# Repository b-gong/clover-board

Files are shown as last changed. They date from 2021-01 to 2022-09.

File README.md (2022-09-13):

# clover-board
Important: This is more of a proof of concept for me and needs a lot of improvement.
- No hotswap; and hotswap sockets don't work because the plate is misaligned by fractions of a mm
- Not a big fan of the layout anymore, too big

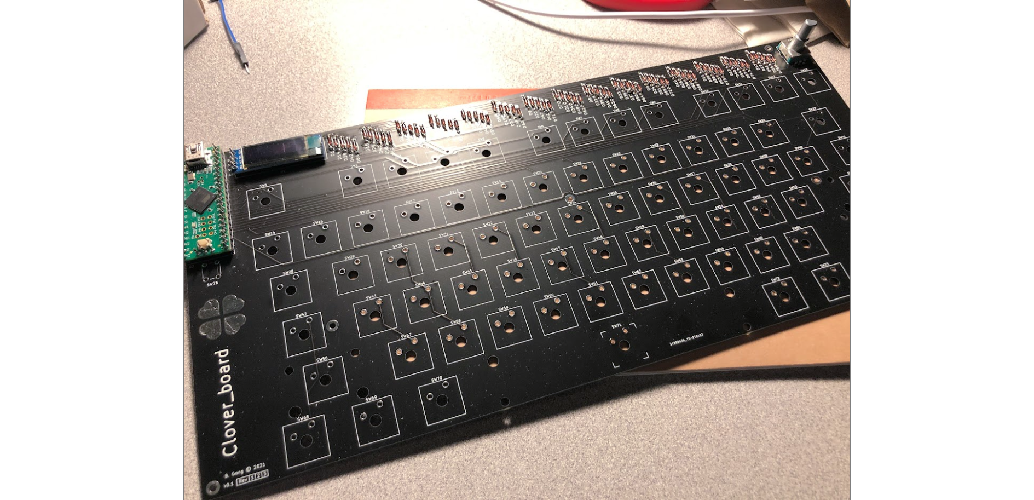
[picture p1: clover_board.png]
Picture of manufactured board


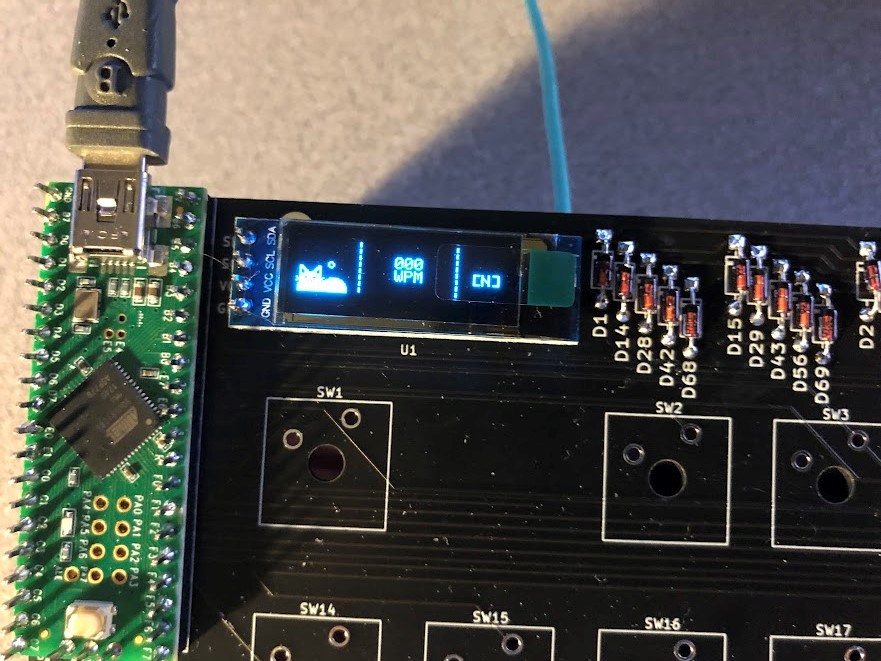
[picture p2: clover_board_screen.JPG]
Picture of OLED screen


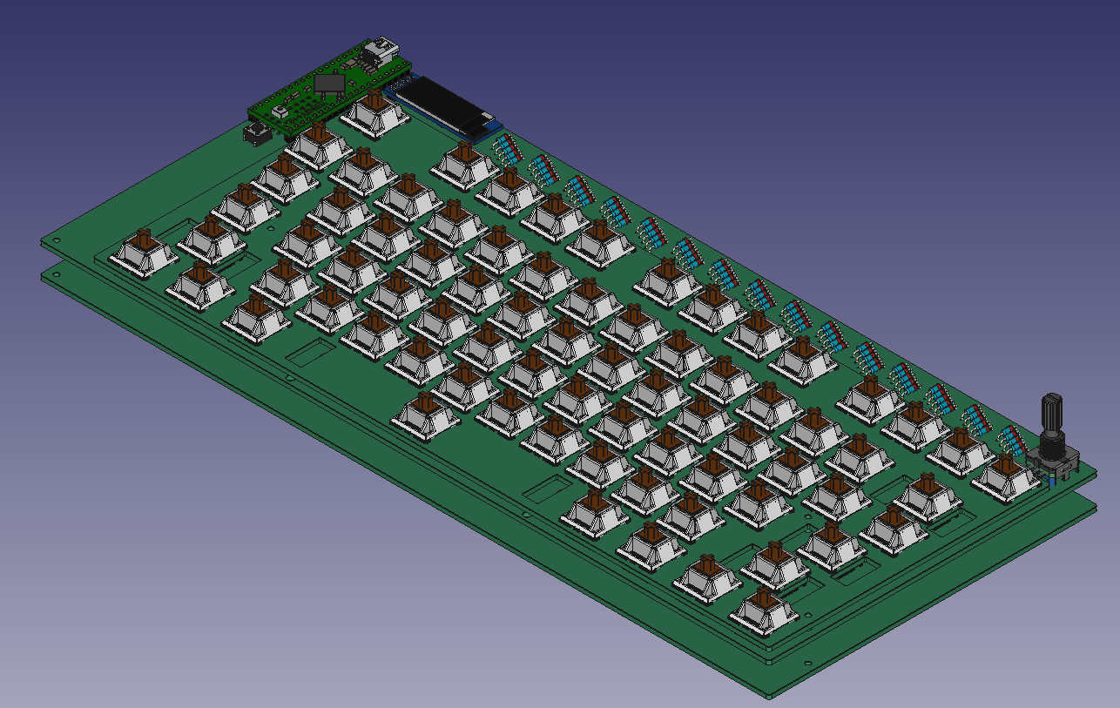
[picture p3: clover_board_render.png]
FreeCAD Screenshot of clover_board made with KiCadStepUp Addon


### 60% + Function Keys with OLED screen and rotary encoder
Who needs the rest of the keyboard xd

### Exposed diodes and Pro Micro for a e s t h e t i c s
Looks sexy

### Namesake of the board (so cute!)
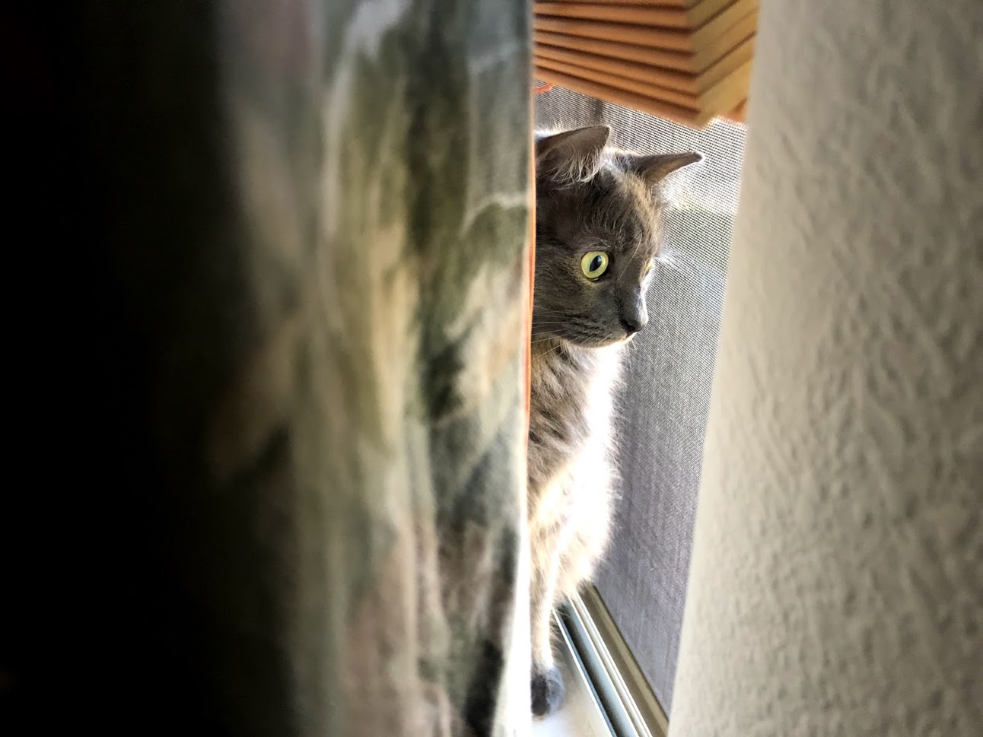
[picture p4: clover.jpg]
Picture of Clover the cat


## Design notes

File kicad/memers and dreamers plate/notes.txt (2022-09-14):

x: [-7.69, 300.51]
y: [32.955, 171.955]

side legnth of square in plate = 270.64375 - 284.64375 = 14mm

distance from rctrl to right and bottom edges in pcb (repectively) = 5.21mm 2.54mm

x coord of rctrl right edge = 300.99-5.21 = 295.78
y coord of rctrl bottom edge = 172.085-2.54 = 169.545

screw holes:
19.5 36.5
280.5 36.5
148.25	95.25 (on plate)
42 124 (on plate)
261 116 (on plate)
-4 168.5
297 152 (on plate)

+5.51 171.955-164.0625

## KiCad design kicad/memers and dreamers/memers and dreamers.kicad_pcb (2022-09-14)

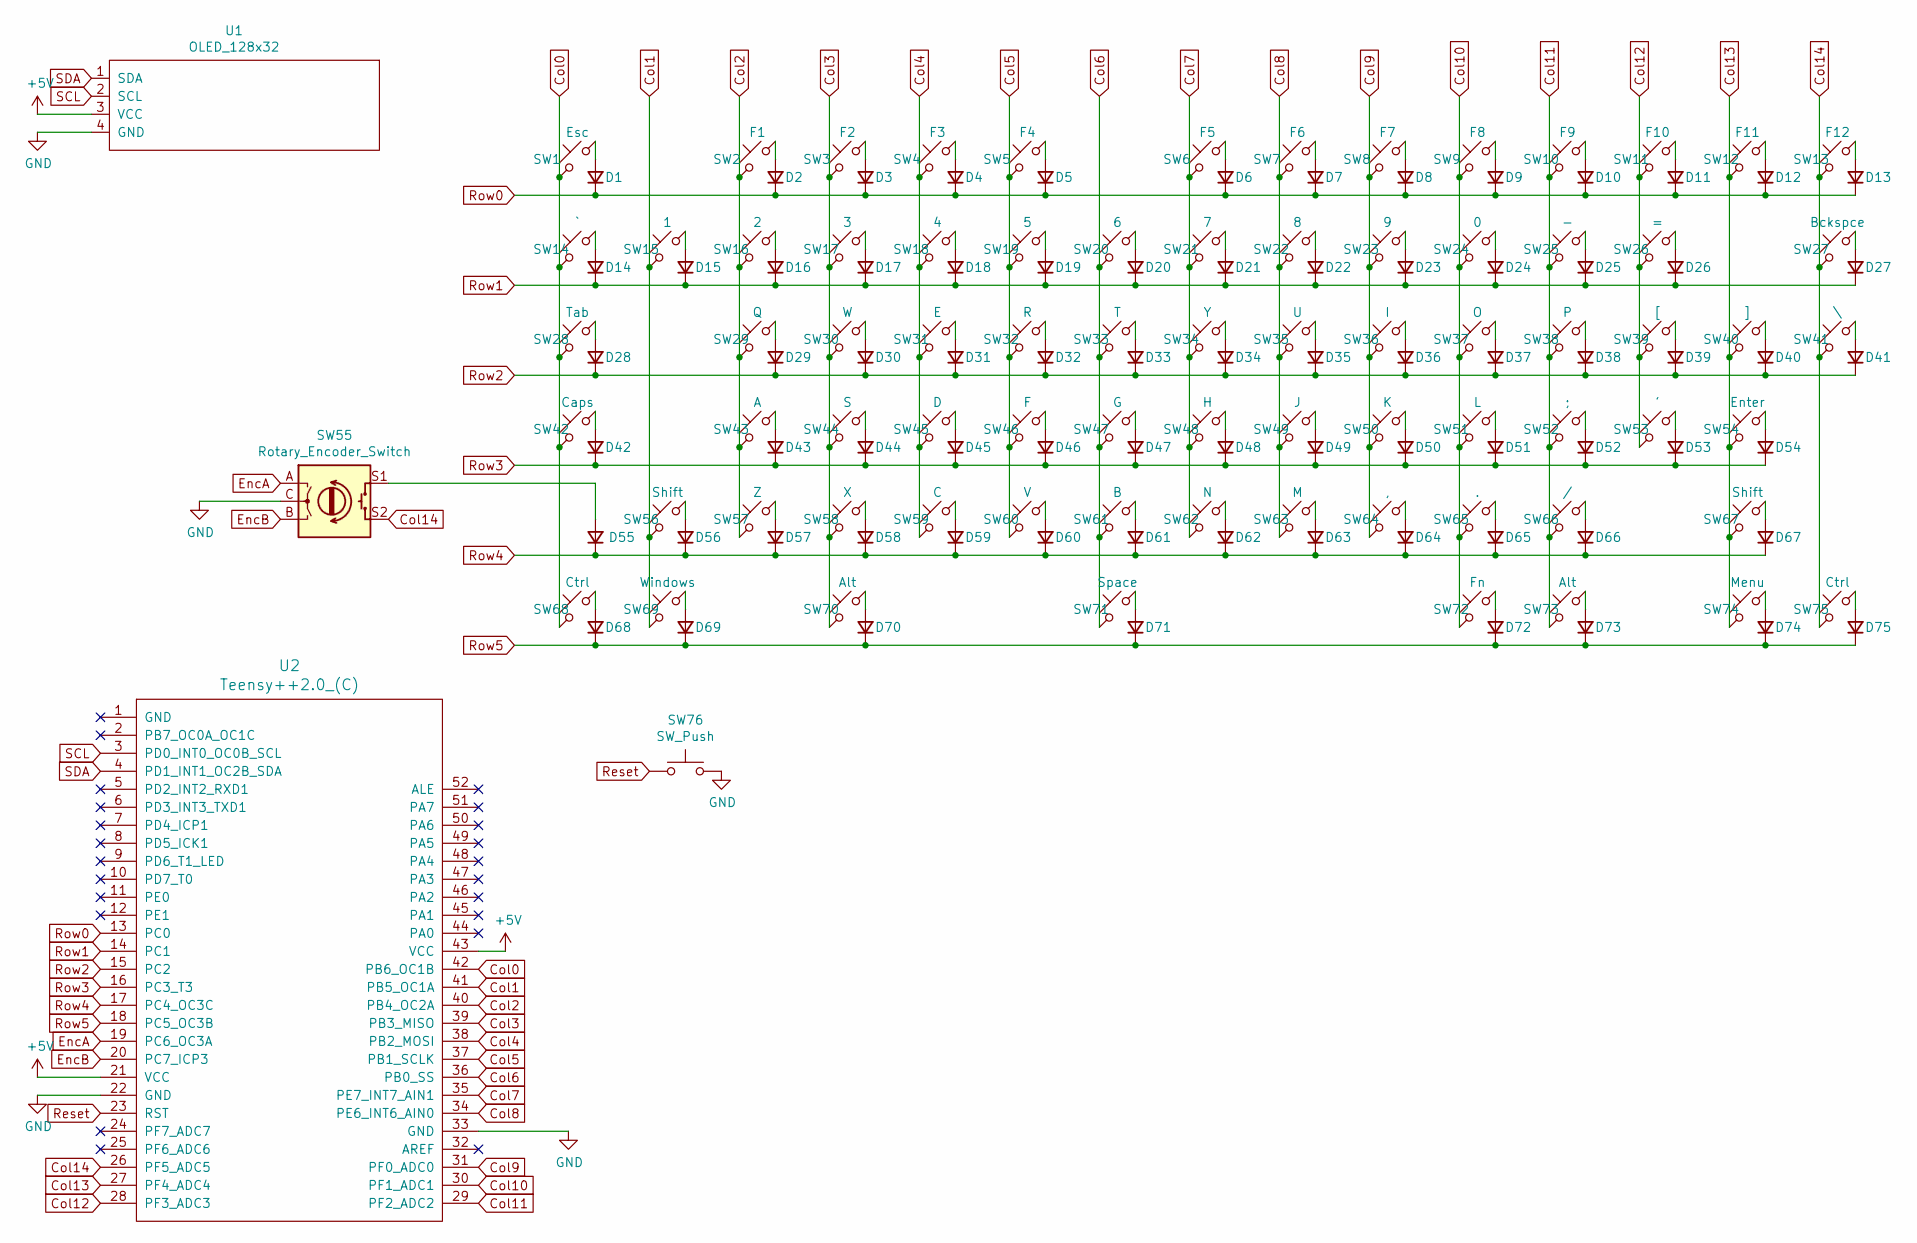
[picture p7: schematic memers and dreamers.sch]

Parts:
D1, D2, D3, D4, D5, D6, D7, D8, D9, D10, D11, D12, D13, D14, D15, D16, D17, D18, D19, D20, D21, D22, D23, D24, D25, D26, D27, D28, D29, D30, D31, D32, D33, D34, D35, D36, D37, D38, D39, D40, D41, D42, D43, D44, D45, D46, D47, D48, D49, D50, D51, D52, D53, D54, D55, D56, D57, D58, D59, D60, D61, D62, D63, D64, D65, D66, D67, D68, D69, D70, D71, D72, D73, D74, D75: D_Small; Diode
SW1: Esc; SW_Cherry_MX_1.00u_Plate
SW2: F1; SW_Cherry_MX_1.00u_Plate
SW3: F2; SW_Cherry_MX_1.00u_Plate
SW4: F3; SW_Cherry_MX_1.00u_Plate
SW5: F4; SW_Cherry_MX_1.00u_Plate
SW6: F5; SW_Cherry_MX_1.00u_Plate
SW7: F6; SW_Cherry_MX_1.00u_Plate
SW8: F7; SW_Cherry_MX_1.00u_Plate
SW9: F8; SW_Cherry_MX_1.00u_Plate
SW10: F9; SW_Cherry_MX_1.00u_Plate
SW11: F10; SW_Cherry_MX_1.00u_Plate
SW12: F11; SW_Cherry_MX_1.00u_Plate
SW13: F12; SW_Cherry_MX_1.00u_Plate
SW14: `; SW_Cherry_MX_1.00u_Plate
SW15: 1; SW_Cherry_MX_1.00u_Plate
SW16: 2; SW_Cherry_MX_1.00u_Plate
SW17: 3; SW_Cherry_MX_1.00u_Plate
SW18: 4; SW_Cherry_MX_1.00u_Plate
SW19: 5; SW_Cherry_MX_1.00u_Plate
SW20: 6; SW_Cherry_MX_1.00u_Plate
SW21: 7; SW_Cherry_MX_1.00u_Plate
SW22: 8; SW_Cherry_MX_1.00u_Plate
SW23: 9; SW_Cherry_MX_1.00u_Plate
SW24: 0; SW_Cherry_MX_1.00u_Plate
SW25: -; SW_Cherry_MX_1.00u_Plate
SW26: =; SW_Cherry_MX_1.00u_Plate
SW27: Bckspce; SW_Cherry_MX_2.00u_Plate
SW28: Tab; SW_Cherry_MX_1.50u_Plate
SW29: Q; SW_Cherry_MX_1.00u_Plate
SW30: W; SW_Cherry_MX_1.00u_Plate
SW31: E; SW_Cherry_MX_1.00u_Plate
SW32: R; SW_Cherry_MX_1.00u_Plate
SW33: T; SW_Cherry_MX_1.00u_Plate
SW34: Y; SW_Cherry_MX_1.00u_Plate
SW35: U; SW_Cherry_MX_1.00u_Plate
SW36: I; SW_Cherry_MX_1.00u_Plate
SW37: O; SW_Cherry_MX_1.00u_Plate
SW38: P; SW_Cherry_MX_1.00u_Plate
SW39: [; SW_Cherry_MX_1.00u_Plate
SW40: ]; SW_Cherry_MX_1.00u_Plate
SW41: \\; SW_Cherry_MX_1.50u_Plate
SW42: Caps; SW_Cherry_MX_1.75u_Plate
SW43: A; SW_Cherry_MX_1.00u_Plate
SW44: S; SW_Cherry_MX_1.00u_Plate
SW45: D; SW_Cherry_MX_1.00u_Plate
SW46: F; SW_Cherry_MX_1.00u_Plate
SW47: G; SW_Cherry_MX_1.00u_Plate
SW48: H; SW_Cherry_MX_1.00u_Plate
SW49: J; SW_Cherry_MX_1.00u_Plate
SW50: K; SW_Cherry_MX_1.00u_Plate
SW51: L; SW_Cherry_MX_1.00u_Plate
SW52: ;; SW_Cherry_MX_1.00u_Plate
SW53: '; SW_Cherry_MX_1.00u_Plate
SW54: Enter; SW_Cherry_MX_2.25u_Plate
SW55: Rotary_Encoder_Switch; RotaryEncoder_EC11
SW56: Shift; SW_Cherry_MX_2.25u_Plate
SW57: Z; SW_Cherry_MX_1.00u_Plate
SW58: X; SW_Cherry_MX_1.00u_Plate
SW59: C; SW_Cherry_MX_1.00u_Plate
SW60: V; SW_Cherry_MX_1.00u_Plate
SW61: B; SW_Cherry_MX_1.00u_Plate
SW62: N; SW_Cherry_MX_1.00u_Plate
SW63: M; SW_Cherry_MX_1.00u_Plate
SW64: ,; SW_Cherry_MX_1.00u_Plate
SW65: .; SW_Cherry_MX_1.00u_Plate
SW66: /; SW_Cherry_MX_1.00u_Plate
SW67: Shift; SW_Cherry_MX_2.75u_Plate
SW68, SW75: Ctrl; SW_Cherry_MX_1.25u_Plate
SW69: Windows; SW_Cherry_MX_1.25u_Plate
SW70, SW73: Alt; SW_Cherry_MX_1.25u_Plate
SW71: Space; SW_Cherry_MX_6.25u_Plate
SW72: Fn; SW_Cherry_MX_1.25u_Plate
SW74: Menu; SW_Cherry_MX_1.25u_Plate
SW76: SW_Push; SW_PUSH_6mm
U1: OLED_128x32
U2: Teensy++2.0_(C); Teensy2.0++

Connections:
+5V: U1.3 (VCC), U2.21 (VCC), U2.43 (VCC)
Col0: SW1.1, SW14.1, SW28.1, SW42.1, SW68.1, U2.42 (PB6_OC1B)
Col1: SW15.1, SW56.1, SW69.1, U2.41 (PB5_OC1A)
Col2: SW2.1, SW16.1, SW29.1, SW43.1, SW57.1, U2.40 (PB4_OC2A)
Col3: SW3.1, SW17.1, SW30.1, SW44.1, SW58.1, SW70.1, U2.39 (PB3_MISO)
Col4: SW4.1, SW18.1, SW31.1, SW45.1, SW59.1, U2.38 (PB2_MOSI)
Col5: SW5.1, SW19.1, SW32.1, SW46.1, SW60.1, U2.37 (PB1_SCLK)
Col6: SW20.1, SW33.1, SW47.1, SW61.1, SW71.1, U2.36 (PB0_SS)
Col7: SW6.1, SW21.1, SW34.1, SW48.1, SW62.1, U2.35 (PE7_INT7_AIN1)
Col8: SW7.1, SW22.1, SW35.1, SW49.1, SW63.1, U2.34 (PE6_INT6_AIN0)
Col9: SW8.1, SW23.1, SW36.1, SW50.1, SW64.1, U2.31 (PF0_ADC0)
Col10: SW9.1, SW24.1, SW37.1, SW51.1, SW65.1, SW72.1, U2.30 (PF1_ADC1)
Col11: SW10.1, SW25.1, SW38.1, SW52.1, SW66.1, SW73.1, U2.29 (PF2_ADC2)
Col12: SW11.1, SW26.1, SW39.1, SW53.1, U2.28 (PF3_ADC3)
Col13: SW12.1, SW40.1, SW54.1, SW67.1, SW74.1, U2.27 (PF4_ADC4)
Col14: SW13.1, SW27.1, SW41.1, SW55.S2, SW75.1, U2.26 (PF5_ADC5)
EncA: SW55.A, U2.19 (PC6_OC3A)
EncB: SW55.B, U2.20 (PC7_ICP3)
GND: SW55.C, SW76.2, U1.4 (GND), U2.22 (GND), U2.33 (GND)
unnamed: D1.2 (A), SW1.2
unnamed: D2.2 (A), SW2.2
unnamed: D3.2 (A), SW3.2
unnamed: D4.2 (A), SW4.2
unnamed: D5.2 (A), SW5.2
unnamed: D6.2 (A), SW6.2
unnamed: D7.2 (A), SW7.2
unnamed: D8.2 (A), SW8.2
unnamed: D9.2 (A), SW9.2
unnamed: D10.2 (A), SW10.2
unnamed: D11.2 (A), SW11.2
unnamed: D12.2 (A), SW12.2
unnamed: D13.2 (A), SW13.2
unnamed: D14.2 (A), SW14.2
unnamed: D15.2 (A), SW15.2
unnamed: D16.2 (A), SW16.2
unnamed: D17.2 (A), SW17.2
unnamed: D18.2 (A), SW18.2
unnamed: D19.2 (A), SW19.2
unnamed: D20.2 (A), SW20.2
unnamed: D21.2 (A), SW21.2
unnamed: D22.2 (A), SW22.2
unnamed: D23.2 (A), SW23.2
unnamed: D24.2 (A), SW24.2
unnamed: D25.2 (A), SW25.2
unnamed: D26.2 (A), SW26.2
unnamed: D27.2 (A), SW27.2
unnamed: D28.2 (A), SW28.2
unnamed: D29.2 (A), SW29.2
unnamed: D30.2 (A), SW30.2
unnamed: D31.2 (A), SW31.2
unnamed: D32.2 (A), SW32.2
unnamed: D33.2 (A), SW33.2
unnamed: D34.2 (A), SW34.2
unnamed: D35.2 (A), SW35.2
unnamed: D36.2 (A), SW36.2
unnamed: D37.2 (A), SW37.2
unnamed: D38.2 (A), SW38.2
unnamed: D39.2 (A), SW39.2
unnamed: D40.2 (A), SW40.2
unnamed: D41.2 (A), SW41.2
unnamed: D42.2 (A), SW42.2
unnamed: D43.2 (A), SW43.2
unnamed: D44.2 (A), SW44.2
unnamed: D45.2 (A), SW45.2
unnamed: D46.2 (A), SW46.2
unnamed: D47.2 (A), SW47.2
unnamed: D48.2 (A), SW48.2
unnamed: D49.2 (A), SW49.2
unnamed: D50.2 (A), SW50.2
unnamed: D51.2 (A), SW51.2
unnamed: D52.2 (A), SW52.2
unnamed: D53.2 (A), SW53.2
unnamed: D54.2 (A), SW54.2
unnamed: D55.2 (A), SW55.S1
unnamed: D56.2 (A), SW56.2
unnamed: D57.2 (A), SW57.2
unnamed: D58.2 (A), SW58.2
unnamed: D59.2 (A), SW59.2
unnamed: D60.2 (A), SW60.2
unnamed: D61.2 (A), SW61.2
unnamed: D62.2 (A), SW62.2
unnamed: D63.2 (A), SW63.2
unnamed: D64.2 (A), SW64.2
unnamed: D65.2 (A), SW65.2
unnamed: D66.2 (A), SW66.2
unnamed: D67.2 (A), SW67.2
unnamed: D68.2 (A), SW68.2
unnamed: D69.2 (A), SW69.2
unnamed: D70.2 (A), SW70.2
unnamed: D71.2 (A), SW71.2
unnamed: D72.2 (A), SW72.2
unnamed: D73.2 (A), SW73.2
unnamed: D74.2 (A), SW74.2
unnamed: D75.2 (A), SW75.2
Reset: SW76.1, U2.23 (RST)
Row0: D1.1 (K), D2.1 (K), D3.1 (K), D4.1 (K), D5.1 (K), D6.1 (K), D7.1 (K), D8.1 (K), D9.1 (K), D10.1 (K), D11.1 (K), D12.1 (K), D13.1 (K), U2.13 (PC0)
Row1: D14.1 (K), D15.1 (K), D16.1 (K), D17.1 (K), D18.1 (K), D19.1 (K), D20.1 (K), D21.1 (K), D22.1 (K), D23.1 (K), D24.1 (K), D25.1 (K), D26.1 (K), D27.1 (K), U2.14 (PC1)
Row2: D28.1 (K), D29.1 (K), D30.1 (K), D31.1 (K), D32.1 (K), D33.1 (K), D34.1 (K), D35.1 (K), D36.1 (K), D37.1 (K), D38.1 (K), D39.1 (K), D40.1 (K), D41.1 (K), U2.15 (PC2)
Row3: D42.1 (K), D43.1 (K), D44.1 (K), D45.1 (K), D46.1 (K), D47.1 (K), D48.1 (K), D49.1 (K), D50.1 (K), D51.1 (K), D52.1 (K), D53.1 (K), D54.1 (K), U2.16 (PC3_T3)
Row4: D55.1 (K), D56.1 (K), D57.1 (K), D58.1 (K), D59.1 (K), D60.1 (K), D61.1 (K), D62.1 (K), D63.1 (K), D64.1 (K), D65.1 (K), D66.1 (K), D67.1 (K), U2.17 (PC4_OC3C)
Row5: D68.1 (K), D69.1 (K), D70.1 (K), D71.1 (K), D72.1 (K), D73.1 (K), D74.1 (K), D75.1 (K), U2.18 (PC5_OC3B)
SCL: U1.2 (SCL), U2.3 (PD0_INT0_OC0B_SCL)
SDA: U1.1 (SDA), U2.4 (PD1_INT1_OC2B_SDA)

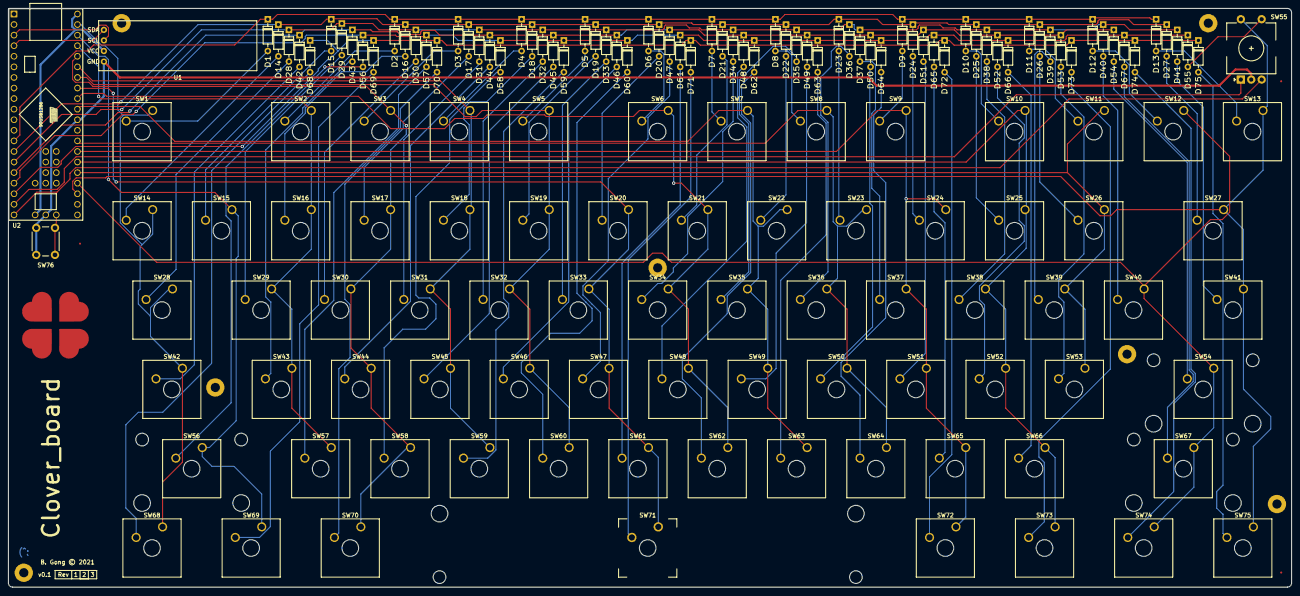
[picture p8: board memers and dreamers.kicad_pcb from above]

Board: 2 copper layers, 308.2 x 139.0 mm, 153 parts (0 on the bottom side), 103 nets.

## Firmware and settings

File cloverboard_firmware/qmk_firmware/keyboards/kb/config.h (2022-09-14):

#ifndef CONFIG_H
#define CONFIG_H

#include "config_common.h"

/* USB Device descriptor parameter */
#define VENDOR_ID       0xFEED
#define PRODUCT_ID      0x6060
#define DEVICE_VER      0x0001
#define MANUFACTURER    qmkbuilder
#define PRODUCT         keyboard
#define DESCRIPTION     Keyboard

/* key matrix size */
#define MATRIX_ROWS 6
#define MATRIX_COLS 15

/* key matrix pins */
#define MATRIX_ROW_PINS { C0, C1, C2, C3, C4, C5 }
#define MATRIX_COL_PINS { B6, B5, B4, B3, B2, B1, B0, E7, E6, F0, F1, F2, F3, F4, F5 }
#define UNUSED_PINS

/* COL2ROW or ROW2COL */
#define DIODE_DIRECTION COL2ROW

/* number of backlight levels */

#ifdef BACKLIGHT_PIN
#define BACKLIGHT_LEVELS 0
#endif

/* Set 0 if debouncing isn't needed */
#define DEBOUNCING_DELAY 5

/* Mechanical locking support. Use KC_LCAP, KC_LNUM or KC_LSCR instead in keymap */
#define LOCKING_SUPPORT_ENABLE

/* Locking resynchronize hack */
#define LOCKING_RESYNC_ENABLE

/* key combination for command */
#define IS_COMMAND() ( \
    keyboard_report->mods == (MOD_BIT(KC_LSHIFT) | MOD_BIT(KC_RSHIFT)) \
)

/* prevent stuck modifiers */
#define PREVENT_STUCK_MODIFIERS


#ifdef RGB_DI_PIN
#define RGBLIGHT_ANIMATIONS
#define RGBLED_NUM 0
#define RGBLIGHT_HUE_STEP 8
#define RGBLIGHT_SAT_STEP 8
#define RGBLIGHT_VAL_STEP 8
#endif

#endif

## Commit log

2021-01-03 added 3d model of the board
2021-01-03 update bottom
    [memers and dreamers bottom.kicad_pcb]
2022-09-14 added firmware and move kicad stuff to its own file
    [memers and dreamers - Copy-B_Cu.gbr, memers and dreamers - Copy-B_Mask.gbr, memers and dreamers - Copy-B_Paste.gbr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]

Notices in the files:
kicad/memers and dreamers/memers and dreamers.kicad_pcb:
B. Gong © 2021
